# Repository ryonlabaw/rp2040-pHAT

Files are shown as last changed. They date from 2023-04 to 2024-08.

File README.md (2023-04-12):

# rp2040-pHAT
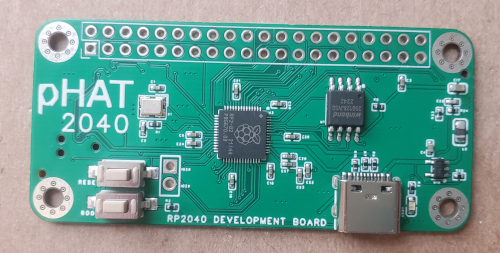
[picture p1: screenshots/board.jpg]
board


Easy to use rp2040 development board.

# header pinout
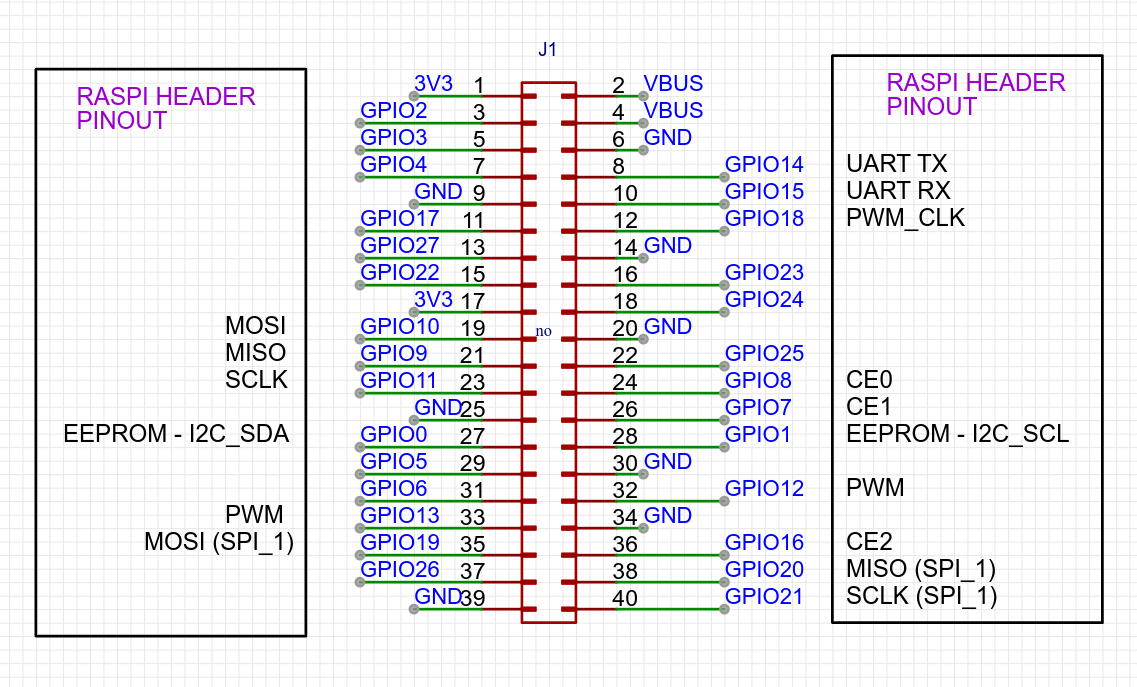
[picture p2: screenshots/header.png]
header pinout


# ADC pinout
The two header pins near the reset + boot switches provide two additional ADC breakout ports.
GPIO 28 + GPIO 29

*all gpio pins on the rp2040 are available*

# using with Raspberry Pi
In order to upload code from the raspberry pi you will need to solder the solder-jumpers on the back of the board.

There are 4 solder jumpers on the back, these allow SWD + UART communication directly between the rp2040 and the raspberry pi host system.

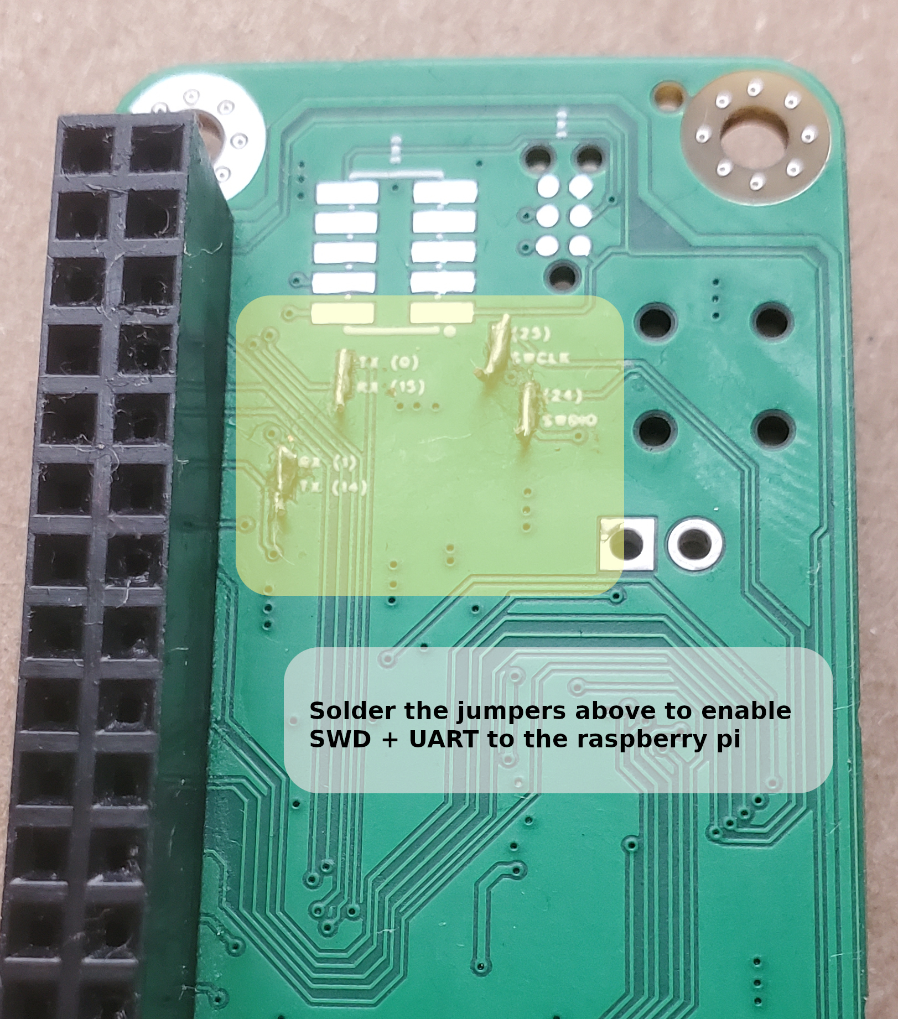
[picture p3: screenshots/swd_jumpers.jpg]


# OpenOCD from Raspberry Pi
see the install_sdk.sh, bash script

If you run that script on the raspberry pi, will setup the pi to allow SWD programming via OpenOCD

You can also manual step thru the commands, just open the file and copy-n-paste the lines manually into your raspberry pi terminal.

# OpenOCD from a Desktop (remote)
You can also start OpenOCD on the PI in remote mode (esp. debugging)

This will allow you to debug the rp2040 from the PI, remotely on your desktop pc (in vccode for example)

# example code
This board is 100% compatible with all rasberry pi pico examples.
See https://github.com/raspberrypi/pico-examples

# UF2 not booting correctly?
If you run into issues using UF2 files via usb, and the device not booting correctly.
There is a timing issue with the rp2040 not booting at times using UF2 files, but the fix is simple.

Add the following line to your CMakeLists.txt file

> add_compile_definitions(PICO_XOSC_STARTUP_DELAY_MULTIPLIER=64)

This will add a small delay to startup to allow booting properly.

This problem doesn't seem to affect SWD uploaded ELF files. So the added flag should not be needed when using SWD.

for more info see:
https://github.com/raspberrypi/pico-sdk/pull/457
https://github.com/raspberrypi/pico-sdk/pull/401

# more examples
there will be more examples available
One neat example code allows using the rp2040-pHAT as an SPI Slave to the raspberry pi board.

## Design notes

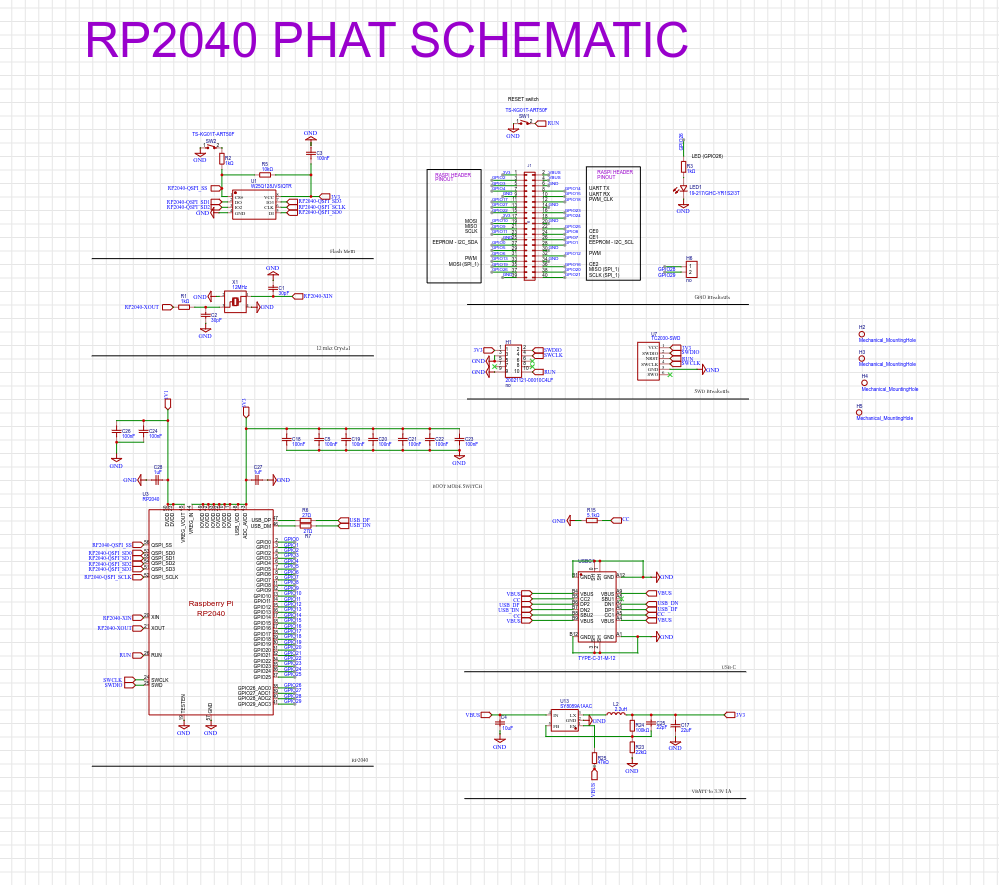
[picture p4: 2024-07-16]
docs/schematic.png

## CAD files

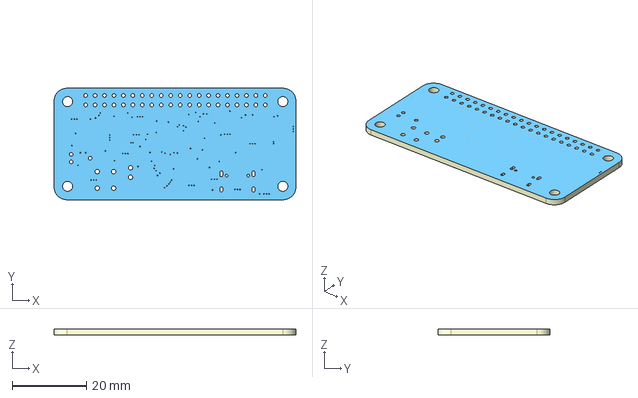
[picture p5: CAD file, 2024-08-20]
docs/rp2040-phat-3d-model.step
65.0 x 30.0 x 1.60 mm

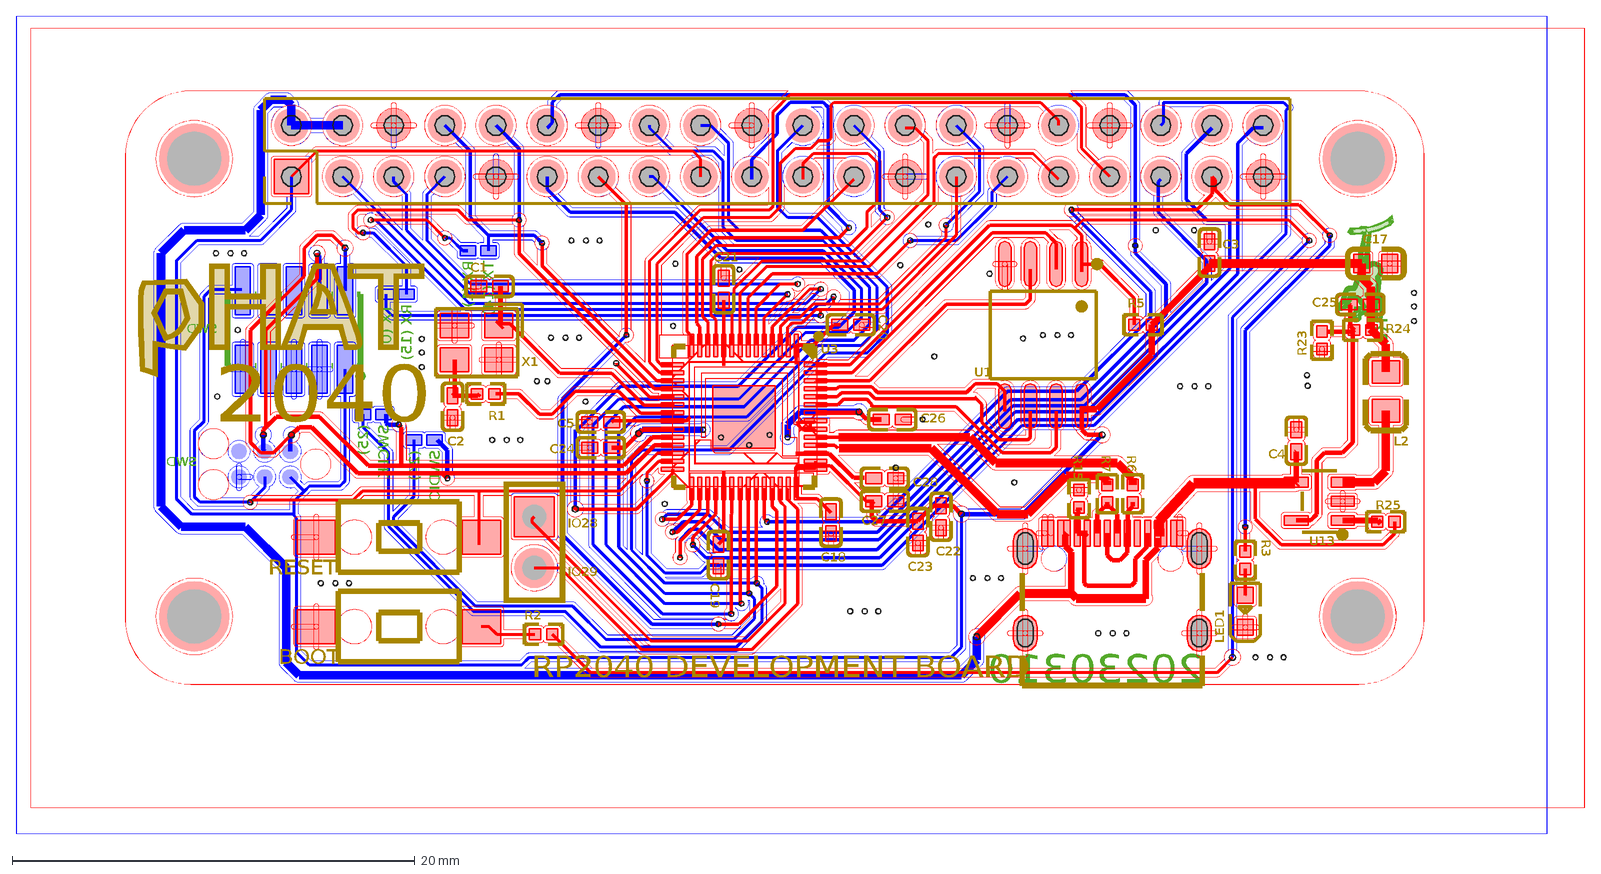
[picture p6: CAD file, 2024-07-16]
docs/rp2040-phat.dxf
SWD
RL
20230310
TX (14)
RX (15)
TX (0)
RX (1)
(25)
SWCLK
(24)
SWDIO
IO29
IO28
RP2040 DEVELOPMENT BOARD
BOOT
RESET
2040
U3
C18
C5
C19
C20
C21
C22
C23
C24
C26
C27
C28
R6
R7
C25
C17
C4
U13
X1
C1
C2
R1
U1
C3
R2
R5
R15
R25
R24
R23
L2
LED1
R3

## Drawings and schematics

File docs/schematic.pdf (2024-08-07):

# RP2040 PHAT SCHEMATIC

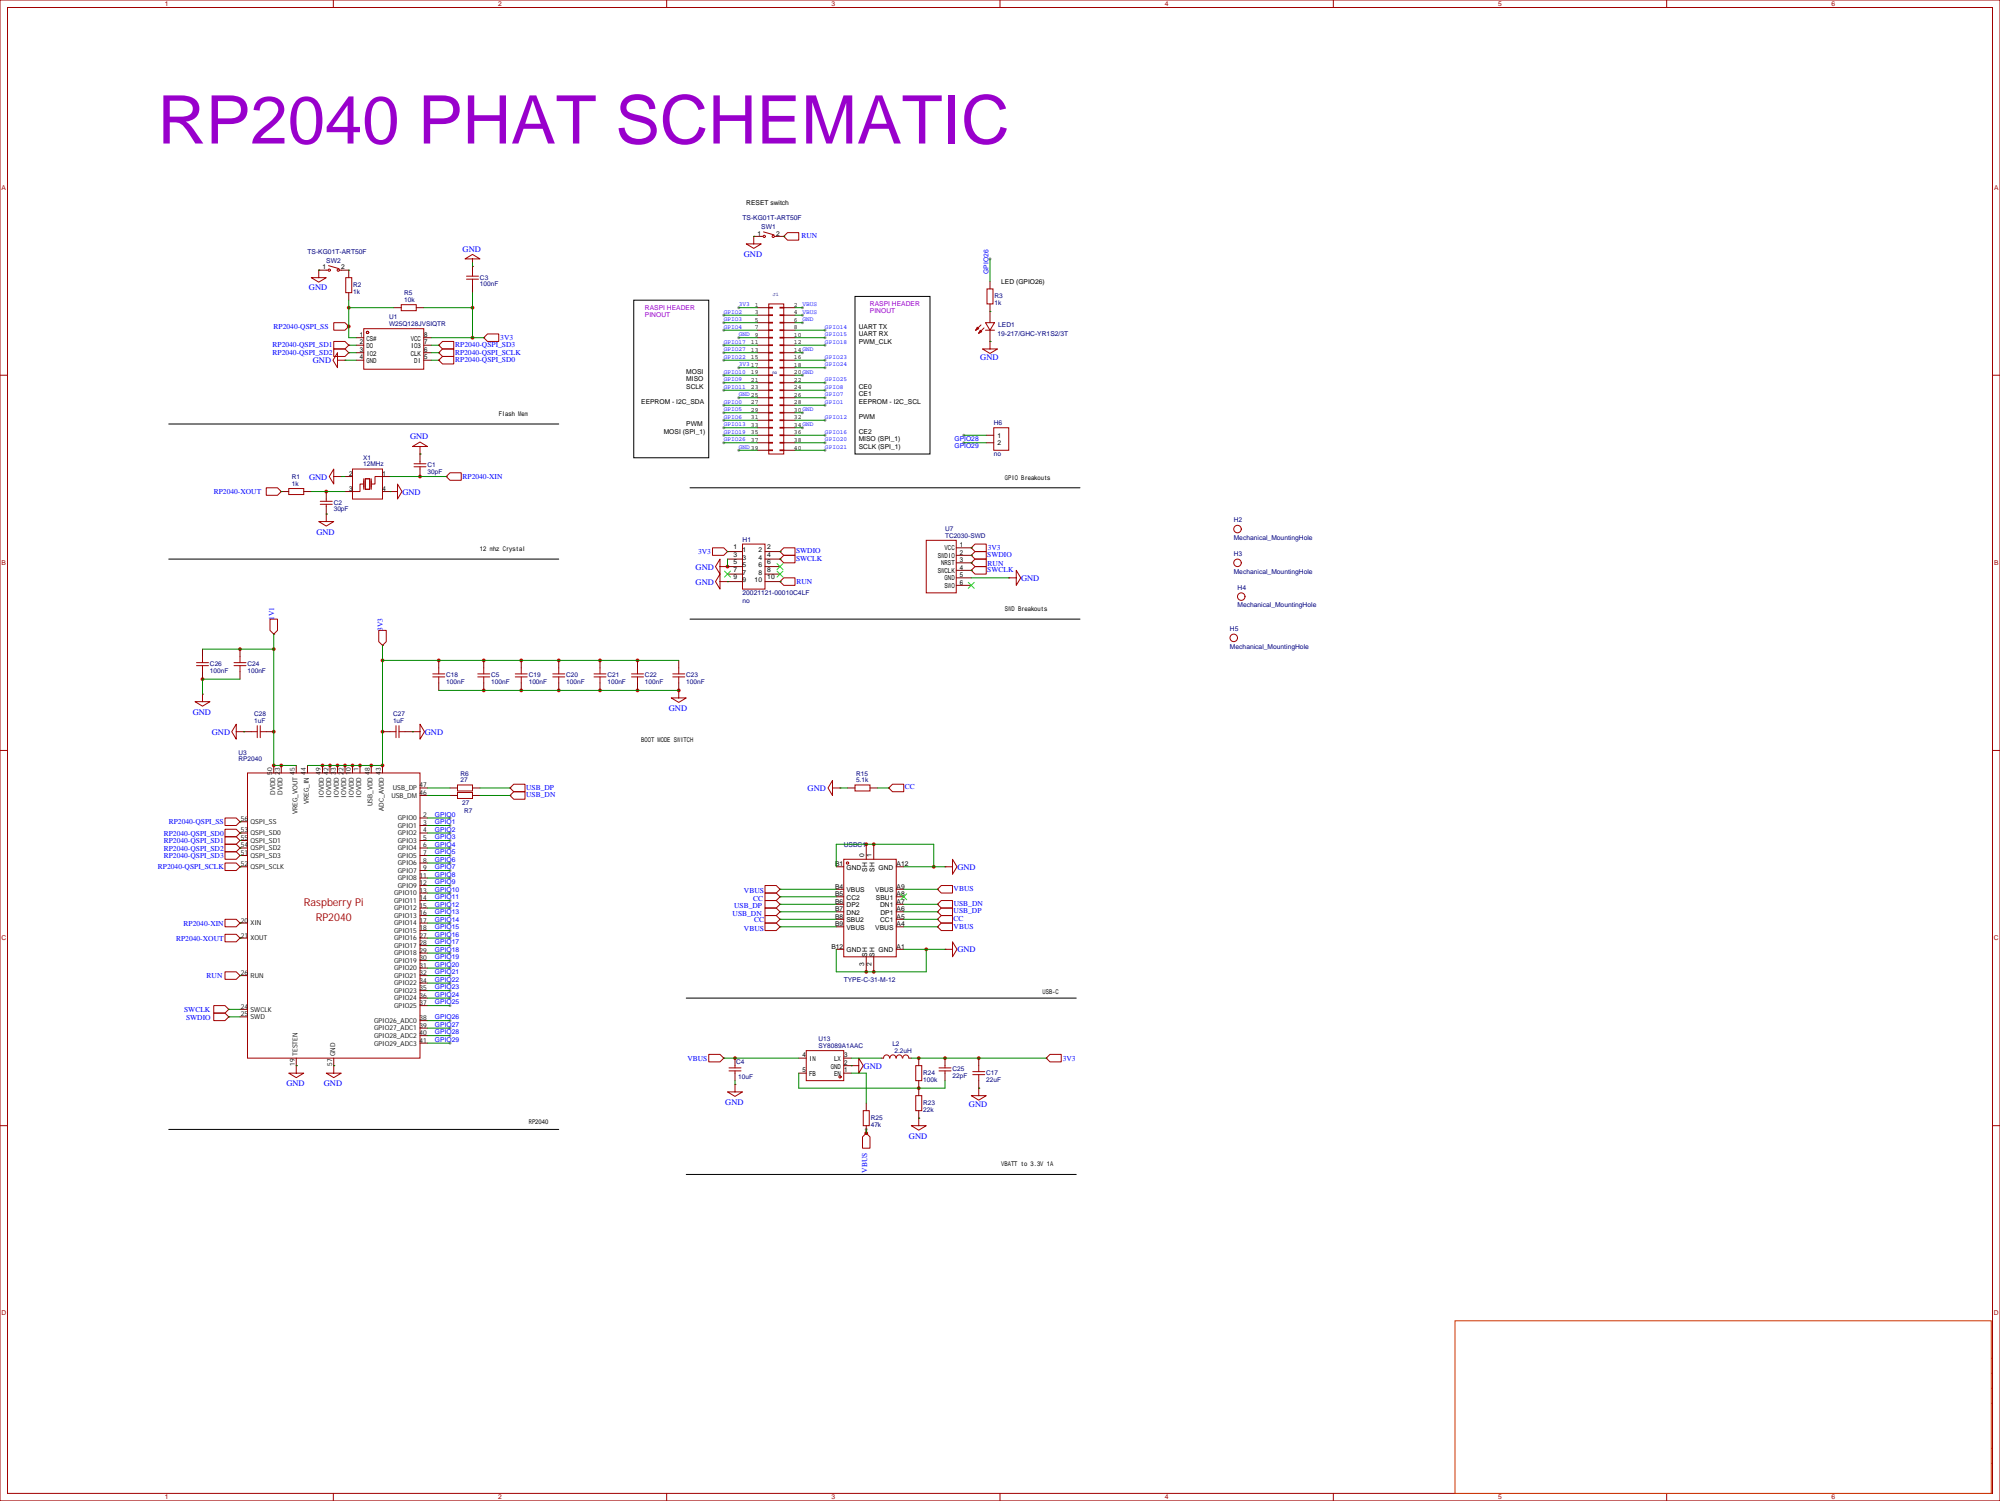
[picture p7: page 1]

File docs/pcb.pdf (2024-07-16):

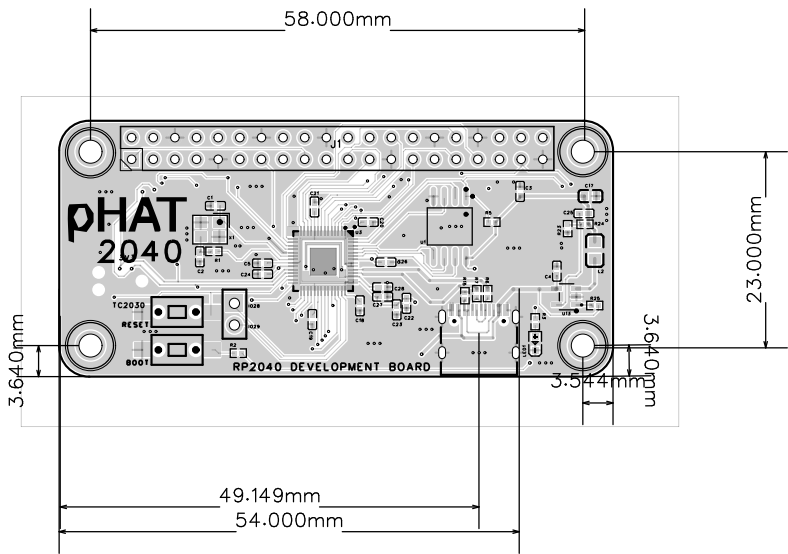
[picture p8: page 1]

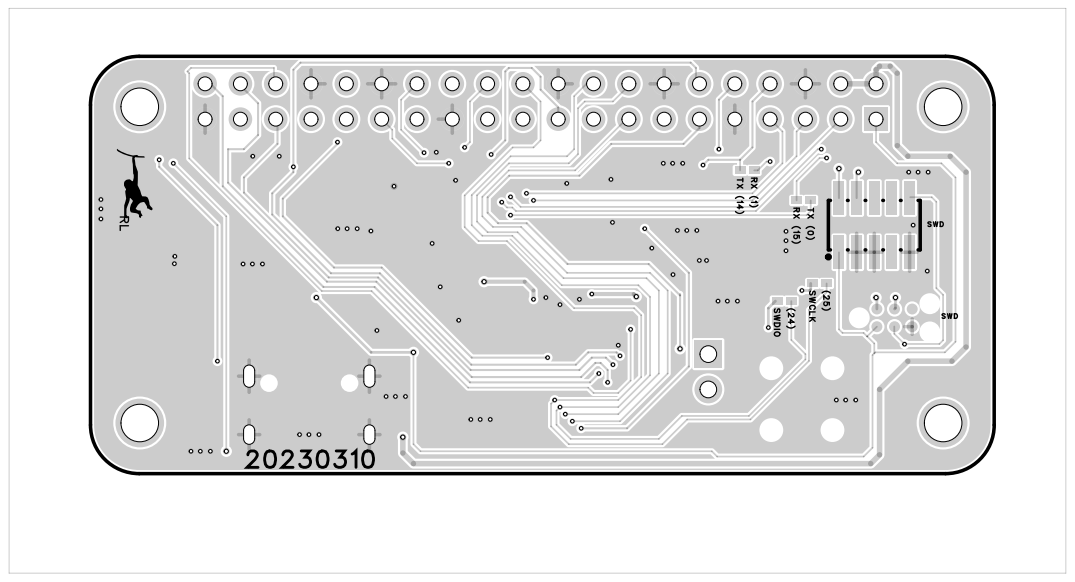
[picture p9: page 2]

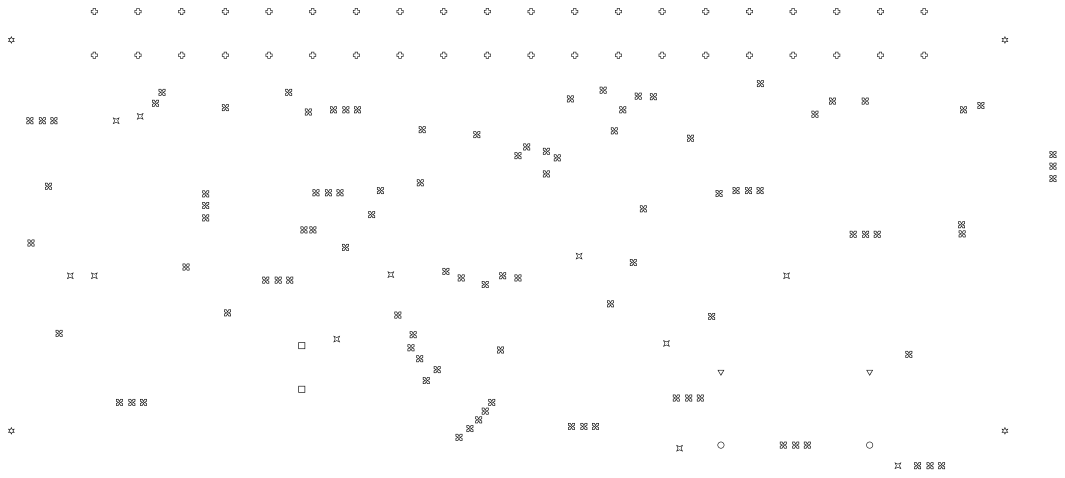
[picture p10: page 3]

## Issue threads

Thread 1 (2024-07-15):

ZeptoForth compatibility?

extrowerk, 2024-07-15:
Hi,

I have found your board on tindie, but because the high shipping costs, I would like to know first if it is comptible with my use-case. Could you please test your board with the latest Zeptoforth build? It should be freely available here: https://github.com/tabemann/zeptoforth/releases
Theoretically it should run just fine, possibly the bigger flash won't be used automatically, but that would be just a matter of a minimal patching.

Thank You!

extrowerk, 2024-07-15:
Also could you provide a 3d model or a drawing about your board so we can incorporate it in our projects?

ryonlabaw, 2024-07-15:
OK, I don't see any reason why zeptoforth would not work. The rp2040-pHat
board is a basic implementation of the rp2040.
I'm kinda busy right now, so I don't have time to set up and test
zeptoforth.

What country are you wanting to ship to?
How many units?
Let me know and perhaps we can work something out.

I can provide an OBJ file, a DXF file and PDF drawing/measurements of the
board.

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

extrowerk, 2024-07-15:
I am located in Hungary / central EU, I need 2 unit only.

I would greatly appreciate if you could upload the OBJ and a PDF drawing so I can design my enclosure around it..

ryonlabaw, 2024-07-16:
Added some files to the docs folder
https://github.com/ryonlabaw/rp2040-pHAT/tree/main/docs

let me know if you need anything else.

extrowerk, 2024-07-16:
Thank You!
I am on my way to build a small device, and your board seems to be the perfect choice. Sadly the OBJ you just posted seems to be somewhat non-accurate: it shows pin-headers which is not shown on the photos. Also it missing some components (rp2040 for example). I am also not exactly sure if there is any components mounted on the bottom side of the PCB. Could you please provide me some info?

Regarding the buttons : is it possible to remove / replace them with a smaller one, or using jumper wires if necessary? I am not from EE, so I naively think it should be possible, but would be nice if you could confirm. Thank You!

ryonlabaw, 2024-07-17:
Not sure why the headers are being exported as a component. The EDA design app used for this board doesn't give an option to customize the exported components.  Maybe its possible to modify the model in your 3d design software?
Here is a version with just the pcb.
https://github.com/ryonlabaw/rp2040-pHAT/blob/main/docs/pcb-only-3d-obj.zip

The buttons are used for re/programming from the usb port.
I would need to know more about your final setup/design to be able to say if you will have success without the buttons.
Maybe, if you upload the code first, then you could remove the buttons.

Are you connecting this device to a raspberry pi?

ryonlabaw, 2024-07-17:
Regarding replacing buttons with jumpers or wires... yes, that is doable.
Just note that the boot button is used momentarily, at bootup. Then it is not used.
Reset button can be used at any time, but is not required. Its momentary as well.
So the jumper/wire would need to be connected and disconnected.

extrowerk, 2024-07-17:
Thanks for  the info. The sw i plan to use is Zeptoforth, and from my understanding i can safely remove the switches after uploading it.
I am working on a small, forth based programming handheld. There is no rpi involved. Instead of that Zeptoforth provides a REPL command-line interface over UART, so I simply connect a dumb terminal (which consist a keyboard + a lcd display) to be able to interact with Zeptoforth on the road and control the GPIO without needing any computer.

I recommend you to try Zeptoforth: it is interesting and can communicate via UART over USB aswell (CDC i think), so you can upload the uf2, then connect to the REPL via terminal over USB.

extrowerk, 2024-08-05:
Thanks for al lthe info you provided already. I am wondering if you could publish a bit better schematics. The [current one](https://github.com/ryonlabaw/rp2040-pHAT/blob/main/docs/schematic.png) is not readable, at least not for my bad eyes. Thanks!

ryonlabaw, 2024-08-07:
Here is a pdf version
https://github.com/ryonlabaw/rp2040-pHAT/blob/main/docs/schematic.pdf

extrowerk, 2024-08-12:
I have received the boards, but you have made a big mistake, I have ordered 2 boards but received 5!

I have just tested it, zeptoforth boots just fine on your pHAT!

ryonlabaw, 2024-08-12:
No mistake. I am just generous to my customers, enjoy.

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

Closed 2024-08-12.

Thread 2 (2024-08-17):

Documentation issue

extrowerk, 2024-08-17:
Hi,

I am trying to build a case around the pHAT, but the available documentation is not adequate for this task.

Just look at this extract from https://github.com/ryonlabaw/rp2040-pHAT/blob/main/docs/pcb.pdf :

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

I don't trust any marked numbers. I was trying to crosschec kit with the supplied https://github.com/ryonlabaw/rp2040-pHAT/blob/main/docs/rp2040-phat.dxf , but something fishy, because I can't get it imported correctly, neither in inch nor in mm and not even in 1:1 mode. I was attempted to find out the scaling rate, which will result correct dimension, but it seems the DXF have different scaling in X and in Y direction. So it skewd or something. I don't know which program made this output, but it not trustworthy.

I belive, this would be the correct outer and interface dimension:

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

However I stil ldon't know where exactly the 40 pin GPIO is.

I am a mechanical engineer, and seemingly you need some support with the drawings, i would be greatful to help you. Feel free to contact me, if you are interested.

Also, while WRML is supported by KiCAD (and probably b the other programs), it is not well situated for mechanical design (it is a triangulated mesh, which therefore not accurate). I would recommend you to create step exports, which is also supported by KiCAD, and it is the industrial platform-independent format for 3D mechanical design.

ryonlabaw, 2024-08-21:
Try this STEP file and see if it offers more accurate dimensions.
https://github.com/ryonlabaw/rp2040-pHAT/blob/main/docs/rp2040-phat-3d-model.step

extrowerk, 2024-08-26:
I just measured the overall dimension of the board, seemingly all dimension differs from the expected nominal size. I can live with hthis, but a correct and clear documentation  would make a much better impression.

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

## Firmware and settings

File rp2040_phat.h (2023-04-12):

/*
 * Copyright (c) 2020 Raspberry Pi (Trading) Ltd.
 *
 * SPDX-License-Identifier: BSD-3-Clause
 */

// -----------------------------------------------------
// NOTE: THIS HEADER IS ALSO INCLUDED BY ASSEMBLER SO
//       SHOULD ONLY CONSIST OF PREPROCESSOR DIRECTIVES
// -----------------------------------------------------

#ifndef _BOARDS_RP2040_PHAT_H
#define _BOARDS_RP2040_PHAT_H

// For board detection
#define RP2040_PHAT

// On some samples, the xosc can take longer to stabilize than is usual
#ifndef PICO_XOSC_STARTUP_DELAY_MULTIPLIER
#define PICO_XOSC_STARTUP_DELAY_MULTIPLIER 64
#endif

//------------- UART -------------//
#ifndef PICO_DEFAULT_UART
#define PICO_DEFAULT_UART 1
#endif

#ifndef PICO_DEFAULT_UART_TX_PIN
#define PICO_DEFAULT_UART_TX_PIN 0
#endif

#ifndef PICO_DEFAULT_UART_RX_PIN
#define PICO_DEFAULT_UART_RX_PIN 1
#endif

//------------- LED -------------//
#ifndef PICO_DEFAULT_LED_PIN
#define PICO_DEFAULT_LED_PIN 26
#endif

//------------- I2C -------------//
#ifndef PICO_DEFAULT_I2C
#define PICO_DEFAULT_I2C 1
#endif

#ifndef PICO_DEFAULT_I2C_SDA_PIN
#define PICO_DEFAULT_I2C_SDA_PIN 2
#endif

#ifndef PICO_DEFAULT_I2C_SCL_PIN
#define PICO_DEFAULT_I2C_SCL_PIN 3
#endif

//------------- SPI -------------//
#ifndef PICO_DEFAULT_SPI
#define PICO_DEFAULT_SPI 0
#endif

#ifndef PICO_DEFAULT_SPI_TX_PIN
#define PICO_DEFAULT_SPI_TX_PIN 19
#endif

#ifndef PICO_DEFAULT_SPI_RX_PIN
#define PICO_DEFAULT_SPI_RX_PIN 20
#endif

#ifndef PICO_DEFAULT_SPI_SCK_PIN
#define PICO_DEFAULT_SPI_SCK_PIN 18
#endif

//------------- FLASH -------------//

#define PICO_BOOT_STAGE2_CHOOSE_W25Q080 1

#ifndef PICO_FLASH_SPI_CLKDIV
#define PICO_FLASH_SPI_CLKDIV 2
#endif

// 16MB of flash
#ifndef PICO_FLASH_SIZE_BYTES
#define PICO_FLASH_SIZE_BYTES (16 * 1024 * 1024)
#endif

// No boards have RP2-B0
#ifndef PICO_RP2040_B0_SUPPORTED
#define PICO_RP2040_B0_SUPPORTED 0
#endif

#endif

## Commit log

2023-04-12 board config file
2024-08-20 3d model in step format
    [rp2040-phat-3d-model.step]
